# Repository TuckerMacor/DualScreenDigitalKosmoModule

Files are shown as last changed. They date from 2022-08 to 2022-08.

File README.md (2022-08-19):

# Dual Screen Digital Kosmo Module

Right now this module is primarily a sequencer but also serves as a digital module software development platform. It has 8 inputs/outputs 2 of which are on a 12 bit DAC that has output circuitry to switch between 0 to 5 volts high resolution or 0 to 10 volts slightly less high resolution, 2 on PWM capable Arduino pins that have a voltage doubler to reach 10 volts, and 4 on analog input pins that can be used as analog inputs or digital outputs.

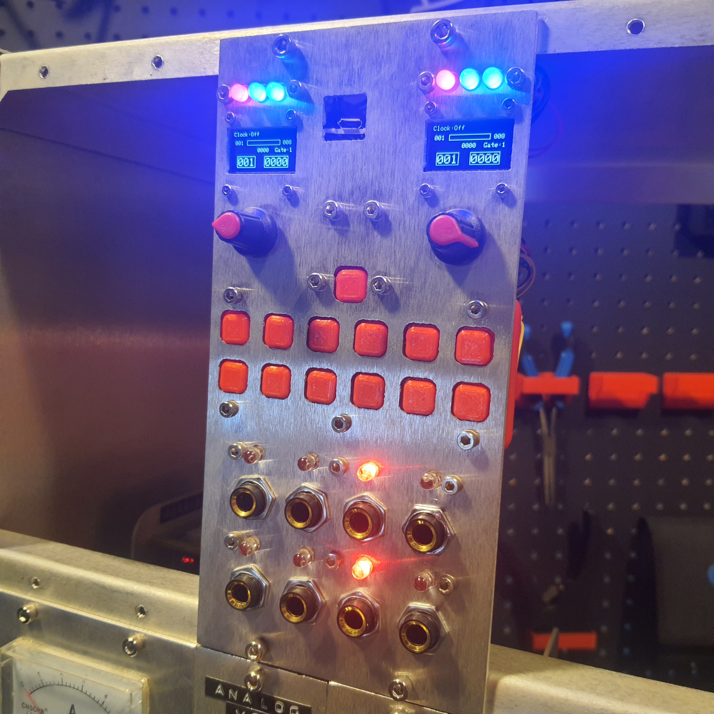
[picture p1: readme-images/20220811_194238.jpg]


# Rack Requirements

#### Power

5 Volt: 150 mA

12 Volt: 10 mA

-12 Volt: 10 mA

#### Size

20 x 5 CM (KOSMO)

# Parts Requirements

#### Electronic

| Part | Amount|
|---|---|
| MCP4922 DAC | 1 |
| TL074 OP-AMP | 1 |
| DIP14 Sockets | 2 |
| Prototyping board | 1 |
| SD Card module | 1 |
| SD Card 2GB or less | 1 |
| RGB Leds | 6 |
| Leds | 8 |
| Arduino Pro Mega | 1 |
| ¼ Jack Sockets | 8 |
| Rotary Encoder | 2 |
| OLED 128x64 | 2 |
| Knobs | 2 |
| Buttons | 13 |
| 10k trimmer | 2 |
| 5k trimmer | 2 |
| 2N3904 transistor | 2 |
| Power connector | 1 |
| Wire | Alot |

#### Resistors

| Value | Amount|
|---|---|
| 1k | 21 |
| 10k | 10 |
| 100k | 4 |
| 470 | 8 |

#### Structure - [Files on GitHub](https://github.com/TuckerMacor/DualScreenDigitalKosmoModule/tree/main/3D%20Prints%20and%20CAD%20Files "GitHub")

| Part | Amount|
|---|---|
| M2 and M3 bolts, nuts ,and standoffs | many |
| Panel - “Panel.dxf” | 1 |
| Mounting shelf - “Shelf.dxf” | 1 |
| Led Mounts - “LedMount.stl” | 2 |
| RGB Led Mounts “RgbMount.stl” | 2 |
| Button Holder “ButtonHolder.stl” | 1 |
| Buttons - “Button.stl” | 13 |

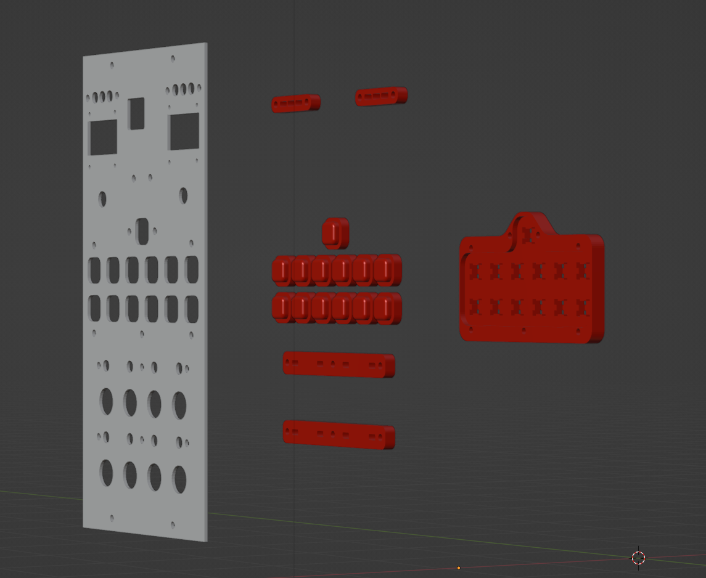
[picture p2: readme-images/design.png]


# Arduino Pin Connections

| | Digital Pins | | Analog Pins |
|-----|---|-----|---|
| D0  | don't use | A0  | INPUT 01 |
| D1  | don't use | A1  | INPUT 02 |
| D2  | encoder 1 | A2  | INPUT 03 |
| D3  | encoder 1 | A3  | INPUT 04 |
| D4  | TRIG OUT A | A4  | free |
| D5  | TRIG OUT B | A5  | Button 11 |
| D6  | Led 01 | A6  | Button 12 |
| D7  | Led 02 | A7  | Button 13 |
| D8  | Led 03 | A8  | Button 14 |
| D9  | Led 04 | A9  | Button 15 |
| D10 | Led 05 | A10 | free |
| D11 | Led 06 | A11 | free |
| D12 | Led 07 | A12 | free |
| D13 | Led 08 | A13 | free |
| D14 | HIGH/LOW RANGE SWITCH A | A14 | free |
| D15 | HIGH/LOW RANGE SWITCH B | A15 | free |
| D16 | RGB LED 01 | | |
| D17 | RGB LED 02 | | |
| D18 | encoder 2 | | |
| D19 | encoder 2 | | |
| D20 | i2c SDA -oleds | | |
| D21 | i2c SCL -oleds | | |
| D22 | RGB LED 03 | | |
| D23 | RGB LED 04 | | |
| D24 | RGB LED 05 | | |
| D25 | RGB LED 06 | | |
| D26 | RGB LED 07 | | |
| D27 | RGB LED 08 | | |
| D28 | RGB LED 09 | | |
| D29 | RGB LED 10 | | |
| D30 | RGB LED 11 | | |
| D31 | RGB LED 12 | | |
| D32 | RGB LED 13 | | |
| D33 | RGB LED 14 | | |
| D34 | RGB LED 15 | | |
| D35 | RGB LED 16 | | |
| D36 | RGB LED 17 | | |
| D37 | RGB LED 18 | | |
| D38 | Button 01 | | |
| D39 | Button 02 | | |
| D40 | Button 03 | | |
| D41 | Button 04 | | |
| D42 | Button 05 | | |
| D43 | Button 06 | | |
| D44 | Button 07 | | |
| D45 | Button 08 | | |
| D46 | Button 09 | | |
| D47 | Button 10 | | |
| D48 | free | | |
| D49 | SPI SD Card CS | | |
| D50 | SPI MISO - DAC -SD | | |
| D51 | SPI MOSI - DAC -SD | | |
| D52 | SPI SCK DAC -SD | | |
| D53 | SPI DAC CS | | |

# ProtoBoard Schematic

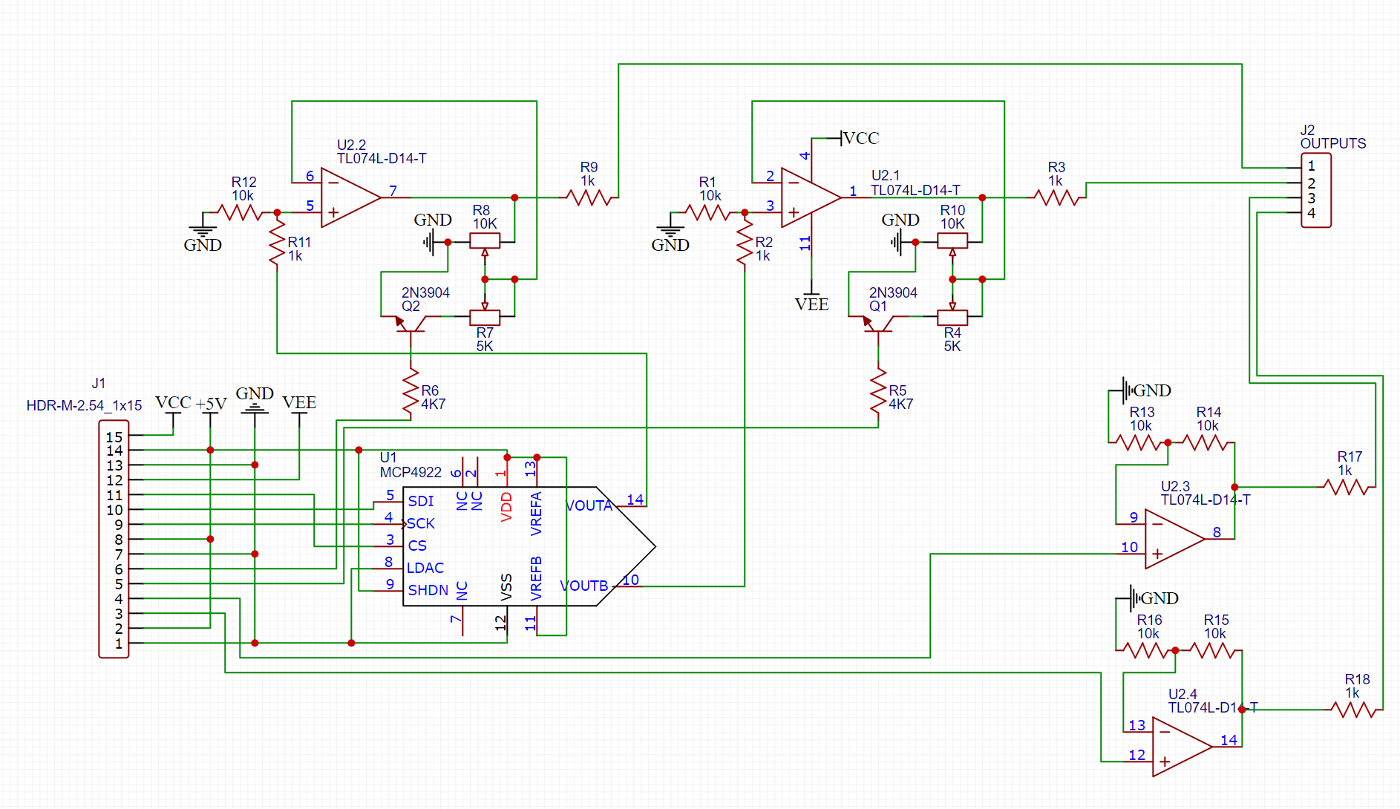
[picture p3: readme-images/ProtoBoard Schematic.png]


## Output Range Switch

The output voltage range of the analog outputs is software adjustable for 0 to 5 volts high resolution or 0 to 10 volts slightly less high res.

# Mod Potential

8 free pins on Arduino

# Software

As of August 12 2022 the software requires the following libraries:

Streaming.h - https://github.com/janelia-arduino/Streaming

SdFat.h - https://github.com/greiman/SdFat

Adafruit_GFX.h - https://github.com/adafruit/Adafruit-GFX-Library

Adafruit_SSD1306.h - https://github.com/adafruit/Adafruit_SSD1306

Encoder.h - https://www.pjrc.com/teensy/td_libs_Encoder.html

MCP_DAC.h - https://github.com/RobTillaart/MCP_DAC

Software is definitely in early versions right now and I'll probably update it a quite few times in the future. If you have suggestions let me know.

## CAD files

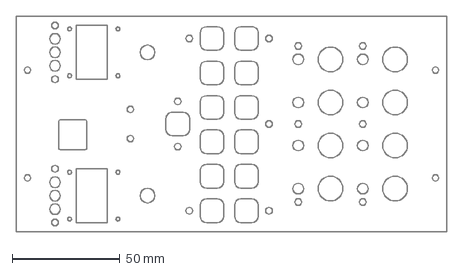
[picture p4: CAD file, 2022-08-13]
3D Prints and CAD Files/Panel.dxf
200.0 x 100.0 mm

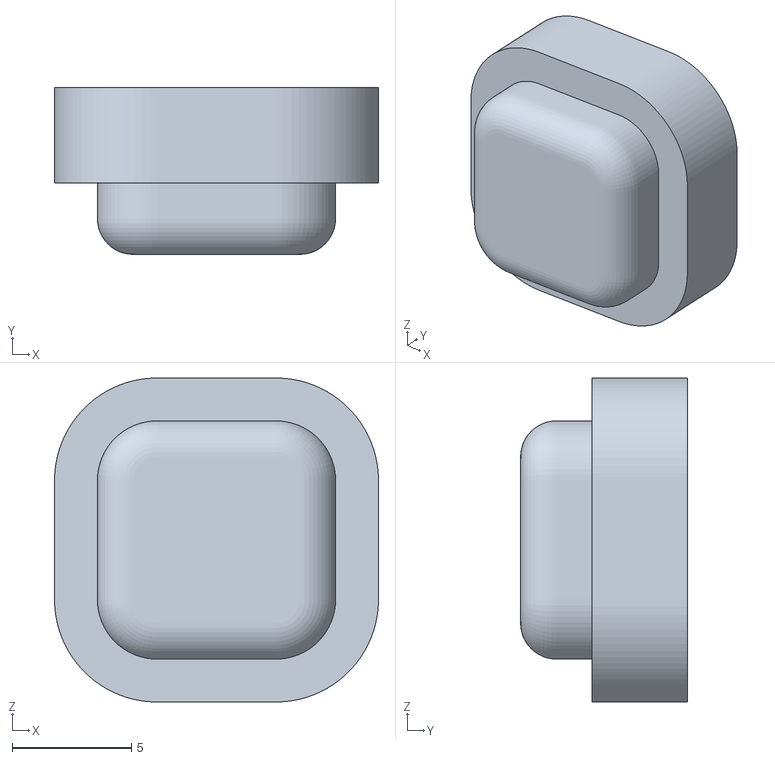
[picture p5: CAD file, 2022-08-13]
3D Prints and CAD Files/Button.stl
13.6 x 7.00 x 13.6

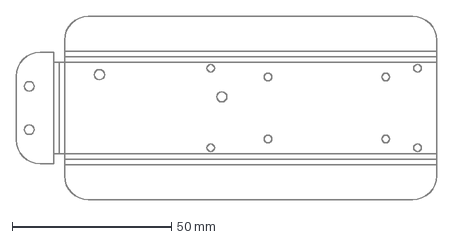
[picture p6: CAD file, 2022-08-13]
3D Prints and CAD Files/Shelf.dxf
132.1 x 57.7 mm

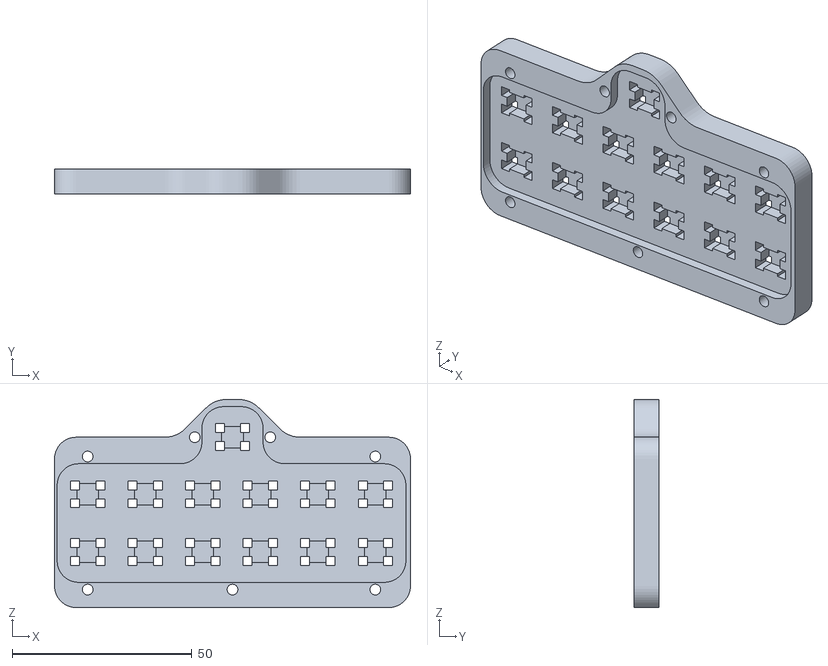
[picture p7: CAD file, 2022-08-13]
3D Prints and CAD Files/ButtonHolder.stl
99.0 x 6.86 x 57.9

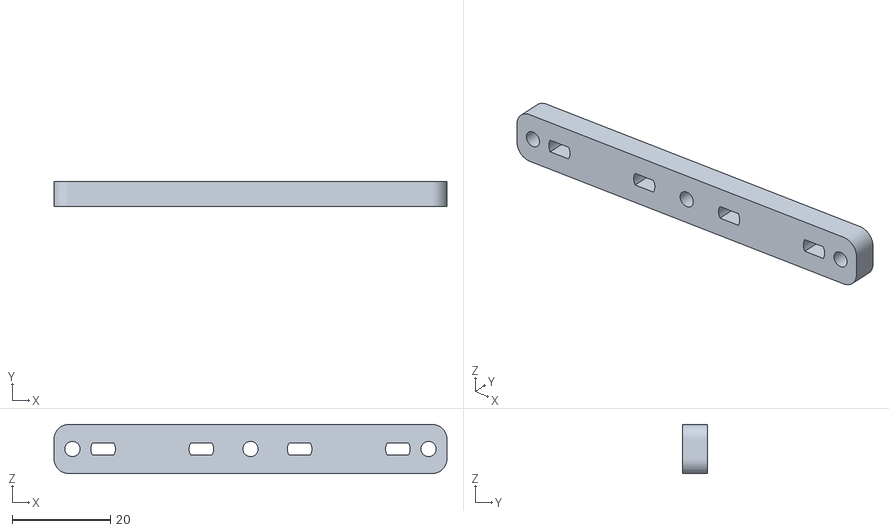
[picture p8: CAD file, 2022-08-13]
3D Prints and CAD Files/LedMount.stl
80.0 x 5.00 x 10.0

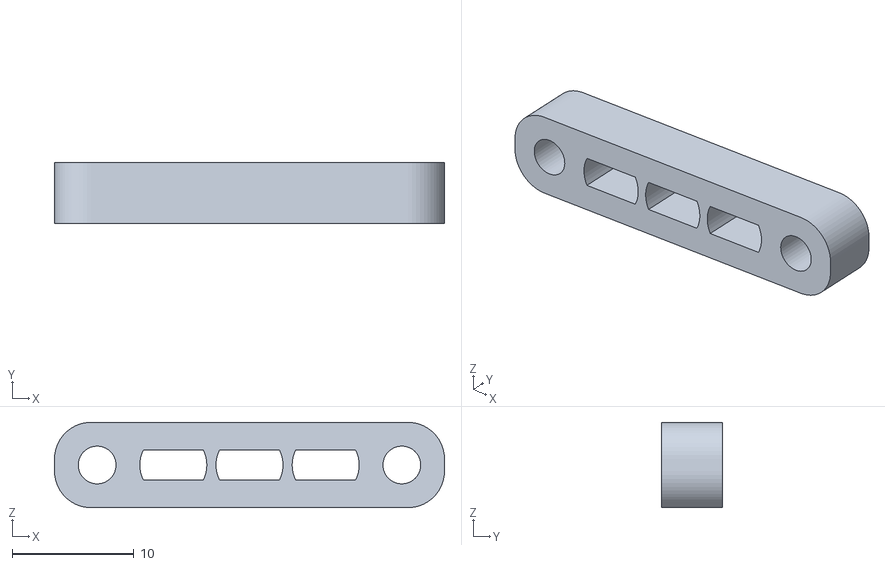
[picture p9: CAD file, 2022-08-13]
3D Prints and CAD Files/RgbMount.stl
32.0 x 5.00 x 7.00

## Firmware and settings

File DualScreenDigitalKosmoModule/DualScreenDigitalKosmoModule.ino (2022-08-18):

#include <SPI.h>
#include <Wire.h>
#include <Streaming.h>
//SD Stuff
#include <SdFat.h>
#define CS_PIN 49 //SPI chip select for sd card
SdFat SD;
File file;
//OLED Stuff
#include <Adafruit_GFX.h>
#include <Adafruit_SSD1306.h>
Adafruit_SSD1306 displayA(128, 64, &Wire);
Adafruit_SSD1306 displayB(128, 64, &Wire);
//Encoder Stuff
#include <Encoder.h>
Encoder Enc1(18, 19); //encoder pins need interupts
Encoder Enc2(2, 3);
long oldPosition[2] = {0, 0};
bool encoderTurn[4] = {0, 0, 0, 0};
//DAC Stuff
#include "MCP_DAC.h"
MCP4922 MCP;  // use HW SPI for DAC
#define dacCS 53 //SPI chip select for DAC
//Pins
#define buttonCount 15
#define LEDCount 8
const int rgbPins[6][3] = { {35, 36, 37}, {32, 33, 34}, {29, 30, 31}, {26, 27, 28}, {23, 24, 25}, {16, 17, 22} };//pins the rgb leds are connected to
const int ledPins[LEDCount] = {6, 7, 8, 9, 10, 11, 12, 13};                                                      //pins the non rgb leds are connected to
const int buttonPins[buttonCount] = {38, 39, 40, 41, 42, 43, 44, 45, 46, 47, A5, A6, A7, A8, A9};                //pins the buttons are connected to
const int rangeSelectPins[2] = {15, 14};                                                                         //pins that change the voltage range
const int gatePins[2] = {5, 4};                                                                                  //pins that control the gate outputs
const int clockInputPins[2] = {A0, A1};                                                                          //pins that get the external clock signal
//button reading variables
bool buttonState[buttonCount];                    //what state is the button at
bool buttonWasPressed[buttonCount];               //was the button pressed
bool lastButtonState[buttonCount];                //previous state of the button
unsigned long lastDebounceTime;
unsigned long debounceDelay = 30;                 //how long to wait before a button is considered pressed
//sequance data variables
int totalStepCount[2] = {7, 7};                    //total amount of steps are in the sequence before repeating
int currentStep[2] = {0, 0};                       //what step is the sequence currently on
boolean currentlyEditingStep[2] = {false, false};  //what value are you changing 0==editing step 2==editing step value 3==gate time 4==gate toggle
int editingStep[2] = {0, 0};                       //which step are you editing
int stepValues[128][2];                            //this is where are the values for every step are stored
int stepGates[128][2];                             //gate mode for this step
int stepGatesAmount[128][2];                       //how many gates for each step
int currentStepGatesAmount[2];                     //how many gates have happend for this step
int clockMode[2] = {1, 1};                         //where should the clock come from? 0=Internal 1=OFF 2=External 3=Sync
bool reverseSequance[2] = {false, false};          //shoud the sequence reverse
float internalClockSpeed = 90;                     //internal Clock Speed in beats per minute
unsigned long lastInternalClock = 0;               //last time the internal clock signal ticked
#define leastInternalClockSpeed 30                 //lowest setable clock speed
#define maxInternalClockSpeed 500                  //highest setable clock speed
#define maxSteps 127                               //max step count (pretty sure changing this will break stuff)
#define minSteps 2                                 //minimum step count
#define ADCMAX 4095                                //max value of the adc
#define maxPerStepGateCount 16                     //max gates per step
//serial debug prints
unsigned long lastSerialPrint = 0;                 //last time the serial data was printed
#define serialPrintInterval -1                     //set to -1 to disable
//other variables
int actionLayer = 0;                              //defines what screen to display and what the buttons should do
/*
   0-99 reserved for sequancer mode
   0=main sequancer page
   1=left step count adjustment
   2=right step count adjustment
   3=internal clock speed adjustment
   4=clock multiply adjustment
   5=left gate time adjustment
   6=right gate time adjustment
   7=save file selection
   8=load file selection
   100-199 reserved for clock mode (planned addition)
   200-299 reserved for random number generator mode (planned addition)
   300-399 reserved for envelope generator mode (planned addition)
   400-499 reserved for clock sync LFO mode (planned addition)
   500-599 reserved for quantizer mode (planned addition)
   600-699 reserved for sample and hold mode (planned addition)
   700-799 reserved for drum sequancer mode (planned addition)
   800-899 reserved for digital VCO mode (not sure if dac is fast enough and won't be able to draw screen when output is working) (planned addition)
   900-999 reserved for alternate sequancer mode (i have an idea for a diffent user interface that could be better but shouldn't replace the existing one) (planned addition)
   1000-1099 reserved for tuner mode to detect frequencies and help tune stuff (planned addition)
*/
bool drawScreen[2] = {true, true};                 //should the oleds be updated
bool rangeSelect[2] = {0, 0};                      //what voltage range to use
int gateTrigger[2] = {0, 0};                       //has a gate been triggerd and in what mode 0=off/1=gate per clock/2=single gate/3=long gate
int gateTime[2] = {50, 50};                        //how long should the gate open for (NOT WORKING PROPERLY updating the oled screen takes a long time and delays the checking for if gates should turn off)
unsigned long gateTriggerTime[2] = {0, 0};         //when was the gate trigged
#define gateMinTime 0                              //minimum gate time
#define gateMaxTime 2000                           //maximum gate time
bool noClockGates = true;                          //should gates open when theres no clock
bool clockInputState[2];                           //state of the clock input
bool lastClockInputState[2];                       //last state of the clock input
unsigned long lastClockInputTime;                  //last time the clock input did somthing
unsigned long clockInputDebounceDelay = 3;         //AHHHHHHHHHHHHHHHHHH
//sd card save and loading variables
const String sequnacerFilePrefix = "SEQ.";                  //start of sequance file names
int saveLoadSelect = 0;                            //which file to save/load from
#define maxSaves 128                               //max amount of save files   (safe to increase if you need)
#define readArrayLength (maxSteps + 1) * 6 + 7     //length of the temporary array that stores data loaded from the sd card
//note to remember to add an overwright file confirmation at some point.


void setup() {
  // put your setup code here, to run once:
  Serial.begin(115200);
  //Setup OLED
  displayA.begin(SSD1306_SWITCHCAPVCC, 0x3C);
  displayB.begin(SSD1306_SWITCHCAPVCC, 0x3D);
  displayA.clearDisplay();
  displayB.clearDisplay();
  displayA.setTextSize(1);
  displayB.setTextSize(1);
  displayA.setTextColor(SSD1306_WHITE);
  displayB.setTextColor(SSD1306_WHITE);
  displayA.setCursor(0, 10);
  displayB.setCursor(0, 10);
  displayA.println(F("Left Display"));
  displayB.println(F("Right Display"));
  //setup sd card
  if (!SD.begin(CS_PIN)) {//if card no work print fail to left screen
    displayA.println(F("SD FAIL"));
  }
  else {
    displayA.println(F("SD Init")); //if sd card works print good
    if (!SD.exists("SequancerModule")) {//check for the sequancer folder
      SD.mkdir("SequancerModule");      //if it's not there make it
    }
    SD.chdir("SequancerModule"); //change to the sequancer folder
  }
  displayA.display();
  displayB.display();
  //dac
  MCP.begin(dacCS);
  //Set Pins as inputs and outputs
  for (byte i = 0; i < buttonCount; i++) {//button pins
    pinMode(buttonPins[i], INPUT_PULLUP);
    buttonWasPressed[i] = false;
  }
  for (byte i = 0; i < LEDCount; i++) {//led pins
    pinMode(ledPins[i], OUTPUT);
    digitalWrite(ledPins[i], HIGH);
    delay(80);
    digitalWrite(ledPins[i], LOW);
  }
  for (byte i = 0; i < 6; i++) {//rgb led pins
    for (byte u = 0; u < 3; u++) {
      pinMode(rgbPins[i][u], OUTPUT);
      digitalWrite(rgbPins[i][u], HIGH);
      delay(80);
      digitalWrite(rgbPins[i][u], LOW);
    }
  }
  for (byte i = 0; i < 128; i++) {//turn on step gates because sound
    for (byte u = 0; u < 2; u++) {
      stepGates[i][u] = HIGH;
      stepGatesAmount[i][u] = 1;
    }
  }
  for (byte i = 0; i < 2; i++) {//range select pins
    pinMode(rangeSelectPins[i], OUTPUT);
    digitalWrite(rangeSelectPins[i], rangeSelect[i]);
  }
  for (byte i = 0; i < 2; i++) {//gate pins
    pinMode(gatePins[i], OUTPUT);
    digitalWrite(gatePins[i], LOW);
  }
  updateRangeSelectLeds();//set the range select leds to the current range select value
  updateclockModeLeds();  //set the clock mode leds to indicate the current clock mode
}


void loop() {
  // put your main code here, to run repeatedly:
  //read inputs
  readButtons();
  buttonActions();
  readEncoders();
  for (byte i = 0; i < 4; i++) {
    if (encoderTurn[i] == true) {
      encoderActions(i);
      encoderTurn[i] = false;
    }
  }
  wrapCursor();//why is this seperate from all the other wraping values?????
  //debug serial print //I turned this off half way through coding so no idea if it still works
  if ((millis() - lastSerialPrint) > serialPrintInterval) {
    Serial << F("Total:") << totalStepCount[0] + 1 << F(" Editing:") << editingStep[0] + 1 << F(" Value:") << stepValues[editingStep[0]][0] << F(" Current:") << currentStep[0] + 1 << F(" Value:") << stepValues[currentStep[0]][0] << F(" | Total:") << totalStepCount[0] + 1 << F(" Editing:") << editingStep[1] + 1 << F(" Value:") << stepValues[editingStep[1]][1] << F(" Current:") << currentStep[1] + 1 << F(" Value:") << stepValues[currentStep[1]][1] << endl;
    lastSerialPrint = millis();
  }
  for (byte i = 0; i < 2; i++) {//if the clock is off match the current step to the editing step
    if (clockMode[i] == 1) {
      currentStep[i] = editingStep[i];
    }
  }
  writeAnalogOutputs();
  internalClock();//do clock stuff
  externalClock();//do other more different clock stuff
  turnOffGates();//check if gates should turn off and if they should turn them off
  for (byte i = 0; i < 2; i++) { //what screen to draw
    if (drawScreen[i] == true) {
      drawScreen[i] = false;
      if (actionLayer == 0 && i == 0) {
        drawSequancerMainPage(0);
      }
      if (actionLayer == 0 && i == 1) {
        drawSequancerMainPage(1);
      }
      else if (actionLayer == 1) {
        drawLeftStepCount();
      }
      else if (actionLayer == 2) {
        drawRightStepCount();
      }
      else if (actionLayer == 3) {
        drawClockSpeed();
      }
      else if (actionLayer == 4) {
        drawClockMultiply();
      }
      else if (actionLayer == 5) {
        drawLeftGateTime();
      }
      else if (actionLayer == 6) {
        drawRightGateTime();
      }
      else if (actionLayer == 7) {
        drawSave();
      }
      else if (actionLayer == 8) {
        drawLoad();
      }
    }
  }
}


void saveSequanceToSD(byte saveSlot) {//saves sequance data as a .csv on the sd card
  String fileName = sequnacerFilePrefix;
  fileName = fileName + saveSlot + ".csv";
  file = SD.open(fileName, FILE_WRITE);
  if (file) {
    file.rewind();
    for (int i = 0; i < 2; i++) {
      for (int u = 0; u < (maxSteps + 1); u++) {
        file.print(stepValues[u][i]);
        if (u < maxSteps) {
          file.print(",");
        }
      }
      if (i < 1) {
        file.print("\r\n");
      }
    }
    file.print("\r\n");
    for (int i = 0; i < 2; i++) {
      for (int u = 0; u < (maxSteps + 1); u++) {
        file.print(stepGates[u][i]);
        if (u < maxSteps) {
          file.print(",");
        }
      }
      if (i < 1) {
        file.print("\r\n");
      }
    }
    file.print("\r\n");
    for (int i = 0; i < 2; i++) {
      for (int u = 0; u < (maxSteps + 1); u++) {
        file.print(stepGatesAmount[u][i]);
        if (u < maxSteps) {
          file.print(",");
        }
      }
      if (i < 1) {
        file.print("\r\n");
      }
    }
    file.print("\r\n");
    file.print(totalStepCount[0]);
    file.print(",");
    file.print(totalStepCount[1]);
    file.print(",");
    file.print(gateTime[0]);
    file.print(",");
    file.print(gateTime[1]);
    file.print(",");
    file.print(clockMode[0]);
    file.print(",");
    file.print(clockMode[1]);
    file.print(",");
    file.print(internalClockSpeed);
    file.close();
  }
  else {
    displayA.clearDisplay();
    displayA.setTextSize(1);
    displayA.setTextColor(SSD1306_WHITE);
    displayA.setCursor(0, 0);
    displayA.println(F("Couldn't Save"));
    displayA.println(F("bad sd card?"));
    displayA.println(F("no sd card?"));
    displayA.display();
    delay(4000);
  }
  actionLayer = 0;
}


void loadSequanceFromSD(byte saveSlot) {//load sequance data from a .csv on the sd card (from the ReadCsvArray example included with SdFat lib)
  String fileName = sequnacerFilePrefix;
  fileName = fileName + saveSlot + ".csv";
  file = SD.open(fileName);
  if (file) {
    file.rewind();
    int tempArrayFromSD[readArrayLength];
    size_t n;
    char str[20];
    char *ptr;
    for (int i = 0; i < (readArrayLength); i++) {
      n = readField(&file, str, sizeof(str), ",\n");
      tempArrayFromSD[i] = strtol(str, &ptr, 10);
      while (*ptr == ' ') {
        ptr++;
      }
    }
    //put the read data in all the right places
    for (int i = 0; i < maxSteps + 1; i++) {
      stepValues[i][0] = tempArrayFromSD[i];
    }
    for (int i = 0; i < maxSteps + 1; i++) {
      stepValues[i][1] = tempArrayFromSD[i + ((maxSteps + 1) * 1)];
    }
    for (int i = 0; i < maxSteps + 1; i++) {
      stepGates[i][0] = tempArrayFromSD[i + ((maxSteps + 1) * 2)];
    }
    for (int i = 0; i < maxSteps + 1; i++) {
      stepGates[i][1] = tempArrayFromSD[i + ((maxSteps + 1) * 3)];
    }
    for (int i = 0; i < maxSteps + 1; i++) {
      stepGatesAmount[i][0] = tempArrayFromSD[i + ((maxSteps + 1) * 4)];
    }
    for (int i = 0; i < maxSteps + 1; i++) {
      stepGatesAmount[i][1] = tempArrayFromSD[i + ((maxSteps + 1) * 5)];
    }
    totalStepCount[0] = tempArrayFromSD[((127 + 1) * 6) + 0];
    totalStepCount[1] = tempArrayFromSD[((127 + 1) * 6) + 1];
    gateTime[0] = tempArrayFromSD[((127 + 1) * 6) + 2];
    gateTime[1] = tempArrayFromSD[((127 + 1) * 6) + 3];
    clockMode[0] = tempArrayFromSD[((127 + 1) * 6) + 4];
    clockMode[1] = tempArrayFromSD[((127 + 1) * 6) + 5];
    internalClockSpeed = tempArrayFromSD[((127 + 1) * 6) + 6];
    file.close();
  }
  else {
    displayA.clearDisplay();
    displayA.setTextSize(1);
    displayA.setTextColor(SSD1306_WHITE);
    displayA.setCursor(0, 0);
    displayA.println(F("Couldn't Load"));
    displayA.println(F("bad file?"));
    displayA.println(F("file dosn't exist?"));
    displayA.display();
    delay(4000);
  }
  actionLayer = 0;
}


void turnOffGates() {//check if gates should turn off and if they should turn them off
  for (byte i = 0; i < 2; i++) {
    if (clockMode[i] == 1 && noClockGates == true) {
      digitalWrite(gatePins[i], HIGH);
      digitalWrite(ledPins[((!i + 1) * 4) - 2], HIGH);
      digitalWrite(rgbPins[((i + 1) * 3) - 2][0], LOW);
      digitalWrite(rgbPins[((i + 1) * 3) - 2][1], LOW);
      digitalWrite(rgbPins[((i + 1) * 3) - 2][2], HIGH);
    }
    else if (millis() - gateTriggerTime[i] > gateTime[i] && (gateTrigger[i] == 1 || (gateTrigger[i] == 2 && currentStepGatesAmount[i] > 0))) {
      digitalWrite(gatePins[i], LOW);
      digitalWrite(ledPins[((!i + 1) * 4) - 2], LOW);
      digitalWrite(rgbPins[((i + 1) * 3) - 2][0], LOW);
      digitalWrite(rgbPins[((i + 1) * 3) - 2][1], LOW);
      digitalWrite(rgbPins[((i + 1) * 3) - 2][2], LOW);
    }
  }
}


void triggerGate(byte whichGate, byte Direction) {//call this to trigger a gate. first value is which gate to trigger and seccond is for led colour to indicate reverse or forwards step
  if (currentStepGatesAmount[whichGate] == stepGatesAmount[currentStep[whichGate]][whichGate]) {
    if (Direction == 1) {
      currentStep[whichGate]--;
      if (currentStep[whichGate] < 0) {
        currentStep[whichGate] = totalStepCount[whichGate];
      }
    }
    else {
      currentStep[whichGate]++;
      if (currentStep[whichGate] > totalStepCount[whichGate]) {
        currentStep[whichGate] = 0;
      }
    }
    currentStepGatesAmount[whichGate] = 0;
  }
  gateTrigger[whichGate] = stepGates[currentStep[whichGate]][whichGate];
  if (gateTrigger[whichGate] == 3 && currentStepGatesAmount[whichGate] == (stepGatesAmount[whichGate] - 1)) {
    gateTrigger[whichGate] = 1;
  }
  writeAnalogOutputs;
  if (gateTrigger[whichGate] == 0) {//no gate
    digitalWrite(gatePins[whichGate], LOW);
    digitalWrite(ledPins[((!whichGate + 1) * 4) - 2], LOW);
    digitalWrite(rgbPins[((whichGate + 1) * 3) - 2][0], LOW);
    digitalWrite(rgbPins[((whichGate + 1) * 3) - 2][1], LOW);
    digitalWrite(rgbPins[((whichGate + 1) * 3) - 2][2], LOW);
  }
  else if (gateTrigger[whichGate] == 1 || ((gateTrigger[whichGate] == 2 || gateTrigger[whichGate] == 3) && currentStepGatesAmount[whichGate] == 0)) {
    digitalWrite(gatePins[whichGate], HIGH);
    digitalWrite(ledPins[((!whichGate + 1) * 4) - 2], HIGH);
    if (Direction == 1) {
      digitalWrite(rgbPins[((whichGate + 1) * 3) - 2][0], HIGH);
      digitalWrite(rgbPins[((whichGate + 1) * 3) - 2][1], LOW);
      digitalWrite(rgbPins[((whichGate + 1) * 3) - 2][2], LOW);
    }
    else {
      digitalWrite(rgbPins[((whichGate + 1) * 3) - 2][0], LOW);
      digitalWrite(rgbPins[((whichGate + 1) * 3) - 2][1], HIGH);
      digitalWrite(rgbPins[((whichGate + 1) * 3) - 2][2], LOW);
    }
  }
  currentStepGatesAmount[whichGate]++;
  gateTriggerTime[whichGate] = millis();
  if (actionLayer == 0) {
    drawScreen[whichGate] = true;
  }
}


void writeAnalogOutputs() {
  MCP.fastWriteB(stepValues[currentStep[0]][0]);
  analogWrite(ledPins[7], map(stepValues[currentStep[0]][0], 0, ADCMAX, 0, 255));
  MCP.fastWriteA(stepValues[currentStep[1]][1]);
  analogWrite(ledPins[3], map(stepValues[currentStep[1]][1], 0, ADCMAX, 0, 255));
}
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
